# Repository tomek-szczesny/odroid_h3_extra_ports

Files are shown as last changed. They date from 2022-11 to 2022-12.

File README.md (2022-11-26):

# odroid_h3_extra_ports

An add-on board for Odroid H3(+) with extra connectivity

- Fits into the H3(+) header directly, or with a ribbon cable.

- Has two M3 mounting holes

- 3x USB 2.0 ports with ESD and overcurrent protection (0.5A)

- 2x I2C ports compatible with Qwiic Connect System

- 1x RS-232 port with RTS/CTS (IDC-10, like on PC motherboards)

- 4-pin header for official power button with LED

- Optional resistor R1 for dimming the power button LED

The PCB is 4-layer, based on 1.6mm JLC7628 stackup.

More information here:

[H3 port extender, extra USB and RS-232 ports - ODROID](https://forum.odroid.com/viewtopic.php?f=172&t=45594)

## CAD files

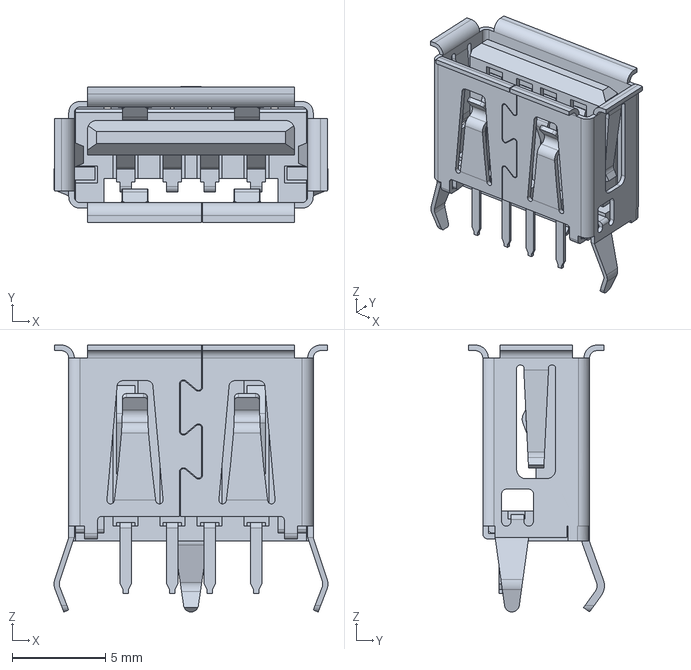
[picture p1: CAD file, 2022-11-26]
1050570001.stp
14.7 x 7.28 x 14.3 mm

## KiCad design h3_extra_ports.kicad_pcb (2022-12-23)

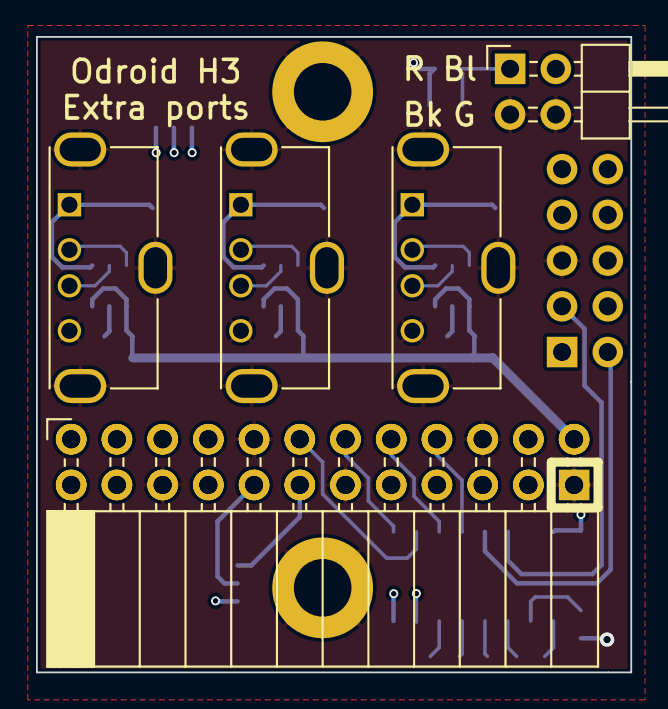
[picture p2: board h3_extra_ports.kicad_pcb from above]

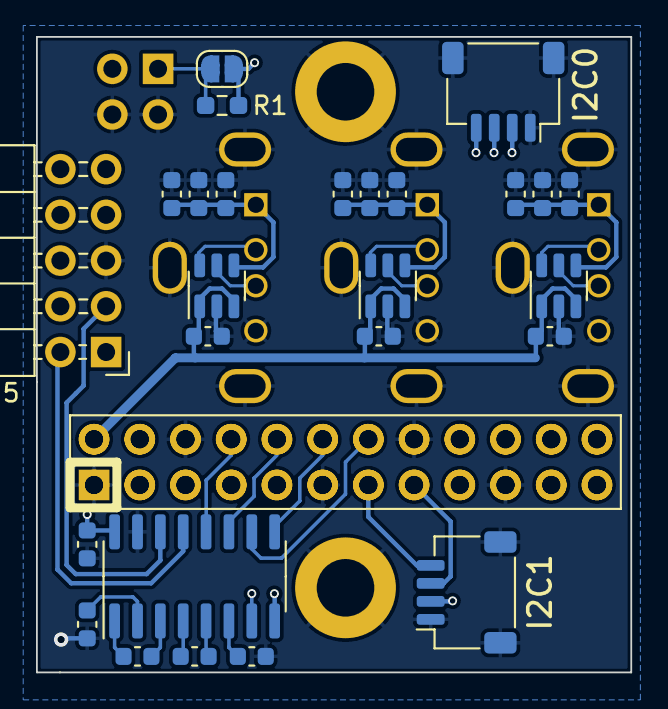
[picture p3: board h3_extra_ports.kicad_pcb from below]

Board: 4 copper layers, 33.0 x 35.3 mm, 34 parts (27 on the bottom side), 34 nets.

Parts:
C1, C3, C4, C5: 100n 16V; C_0603_1608Metric
C2: 1u 16V; C_0603_1608Metric
C6, C10, C14: 100n; C_0603_1608Metric
C7, C8, C9, C11, C12, C13, C15, C16, C17: 47u; C_0603_1608Metric
H1, H2: MountingHole_Pad; MountingHole_3.2mm_M3_DIN965_Pad
J1, J2, J3: USB_A; USB_A_Molex_105057_Vertical
J4: Conn_02x02_Odd_Even; PinHeader_2x02_P2.54mm_Horizontal
J5: RS232; PinHeader_2x05_P2.54mm_Horizontal
J6: Conn_02x12_Odd_Even; PinSocket_2x12_P2.54mm_Horizontal
J7, J8: Qwiik; JST_SH_SM04B-SRSS-TB_1x04-1MP_P1.00mm_Horizontal
J9: Conn_02x12_Odd_Even; PinHeader_2x12_P2.54mm_Vertical
JP1: Solder Jumper; SolderJumper-2_P1.3mm_Open_RoundedPad1.0x1.5mm
R1: DNI; R_0603_1608Metric_Pad0.98x0.95mm_HandSolder
U1: MAX3232; SOIC-16_3.9x9.9mm_P1.27mm
U2, U3, U4: TPD3S014; SOT-23-6

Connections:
/+3.3V_RUN_H: C2.2, J6.21, J7.2, J8.2, J9.4, JP1.2 (B), R1.2, U1.16 (VCC)
/+5V_RUN_H: C6.1, C10.1, C14.1, J6.23, J9.2, U2.1 (EN), U2.3 (IN), U3.1 (EN), U3.3 (IN), U4.1 (EN), U4.3 (IN)
/+V5P0A: J6.1, J9.24
/HDMI_CEC: J6.3, J9.22
/I2C_0_SCL: J6.7, J7.4, J9.18
/I2C_0_SDA: J6.5, J7.3, J9.20
/I2C_1_SCL: J6.12, J8.4, J9.13
/I2C_1_SDA: J6.10, J8.3, J9.15
/PWR_BTN#: J4.2, J6.8, J9.17
/RS232_CTS: J5.8, U1.8 (R2IN)
/RS232_RTS: J5.7, U1.7 (T2OUT)
/RS232_RX: J5.2, U1.13 (R1IN)
/RS232_TX: J5.3, U1.14 (T1OUT)
/UART0_CTS#: J6.13, J9.12, U1.9 (R2OUT)
/UART0_RTS#: J6.11, J9.14, U1.10 (T2IN)
/UART0_RXD: J6.17, J9.8, U1.12 (R1OUT)
/UART0_TXD: J6.15, J9.10, U1.11 (T1IN)
/USB2_P5_DN: J1.2 (D-), J6.16, J9.9, U2.6 (D2)
/USB2_P5_DP: J1.3 (D+), J6.18, J9.7, U2.5 (D1)
/USB2_P6_DN: J2.2 (D-), J6.2, J9.23, U3.6 (D2)
/USB2_P6_DP: J2.3 (D+), J6.4, J9.21, U3.5 (D1)
/USB2_P7_DN: J3.2 (D-), J6.20, J9.5, U4.6 (D2)
/USB2_P7_DP: J3.3 (D+), J6.22, J9.3, U4.5 (D1)
GND: C2.1, C4.1, C5.1, C6.2, C7.1, C8.1, C9.1, C10.2, C11.1, C12.1, C13.1, C14.2, C15.1, C16.1, C17.1, H1.1, H2.1, J1.4 (GND), J1.5 (Shield), J2.4 (GND), J2.5 (Shield), J3.4 (GND), J3.5 (Shield), J4.3, J4.4, J5.5, J6.6, J6.9, J6.14, J6.19, J6.24, J7.1, J7.MP (MountPin), J8.1, J8.MP (MountPin), J9.1, J9.6, J9.11, J9.16, J9.19, U1.15 (GND), U2.2 (GND), U3.2 (GND), U4.2 (GND)
unnamed: C1.1, U1.1 (C1+)
unnamed: C1.2, U1.3 (C1-)
unnamed: C3.1, U1.5 (C2-)
unnamed: C3.2, U1.4 (C2+)
unnamed: C4.2, U1.2 (VS+)
unnamed: C5.2, U1.6 (VS-)
unnamed: C8.2, C9.2, J1.1 (VBUS), U2.4 (OUT)
unnamed: C12.2, C13.2, J2.1 (VBUS), U3.4 (OUT)
unnamed: C16.2, C17.2, J3.1 (VBUS), U4.4 (OUT)
unnamed: J4.1, JP1.1 (A), R1.1

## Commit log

2022-11-26 Added production files
    [h3_extra_ports-B_Cu.gbr, h3_extra_ports-B_Mask.gbr, h3_extra_ports-B_Paste.gbr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]
2022-12-23 Final design - first batch
    [h3_extra_ports-B_Cu.gbr, h3_extra_ports-B_Mask.gbr, h3_extra_ports-B_Paste.gbr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]
